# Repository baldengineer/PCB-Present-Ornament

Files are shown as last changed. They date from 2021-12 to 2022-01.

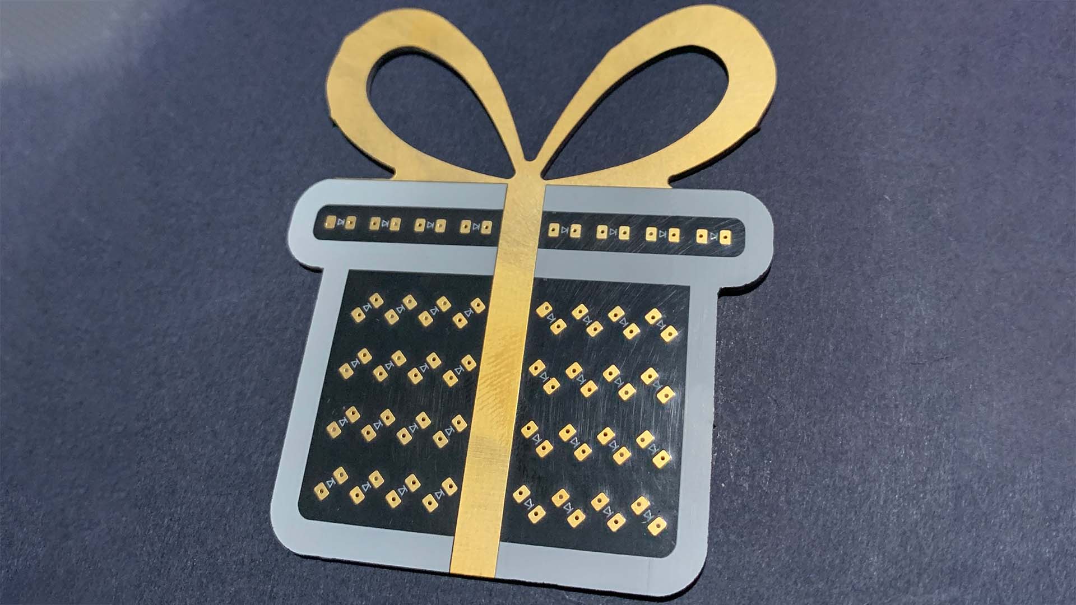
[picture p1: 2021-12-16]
images/pcb-present-oshpark-after-dark.jpg

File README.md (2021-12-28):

Present in OSH Park After Dark

## KiCad Present / Ornament
KiCad stuff.

## Warning: JST is not compatible with Adafruit batteries. + and - are reversed :(

* LED Matrix
* ATmega8 (328) based
* Powered by LiPo
* Programmed with ISP Header
* hand it with a string around the ribbon loops

## Bald Engineer Live Stream
Watch the stream and help out in chat here:
https://twitch.tv/baldengineer

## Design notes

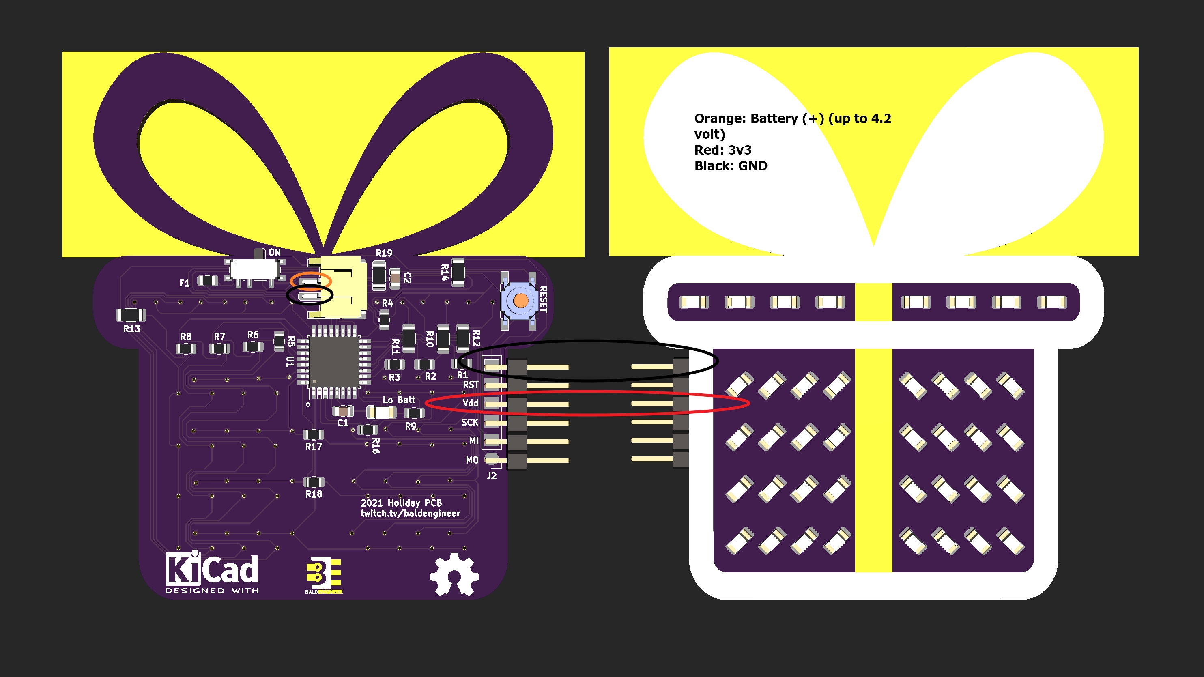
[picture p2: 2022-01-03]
images/powering pcb present annotated.jpg

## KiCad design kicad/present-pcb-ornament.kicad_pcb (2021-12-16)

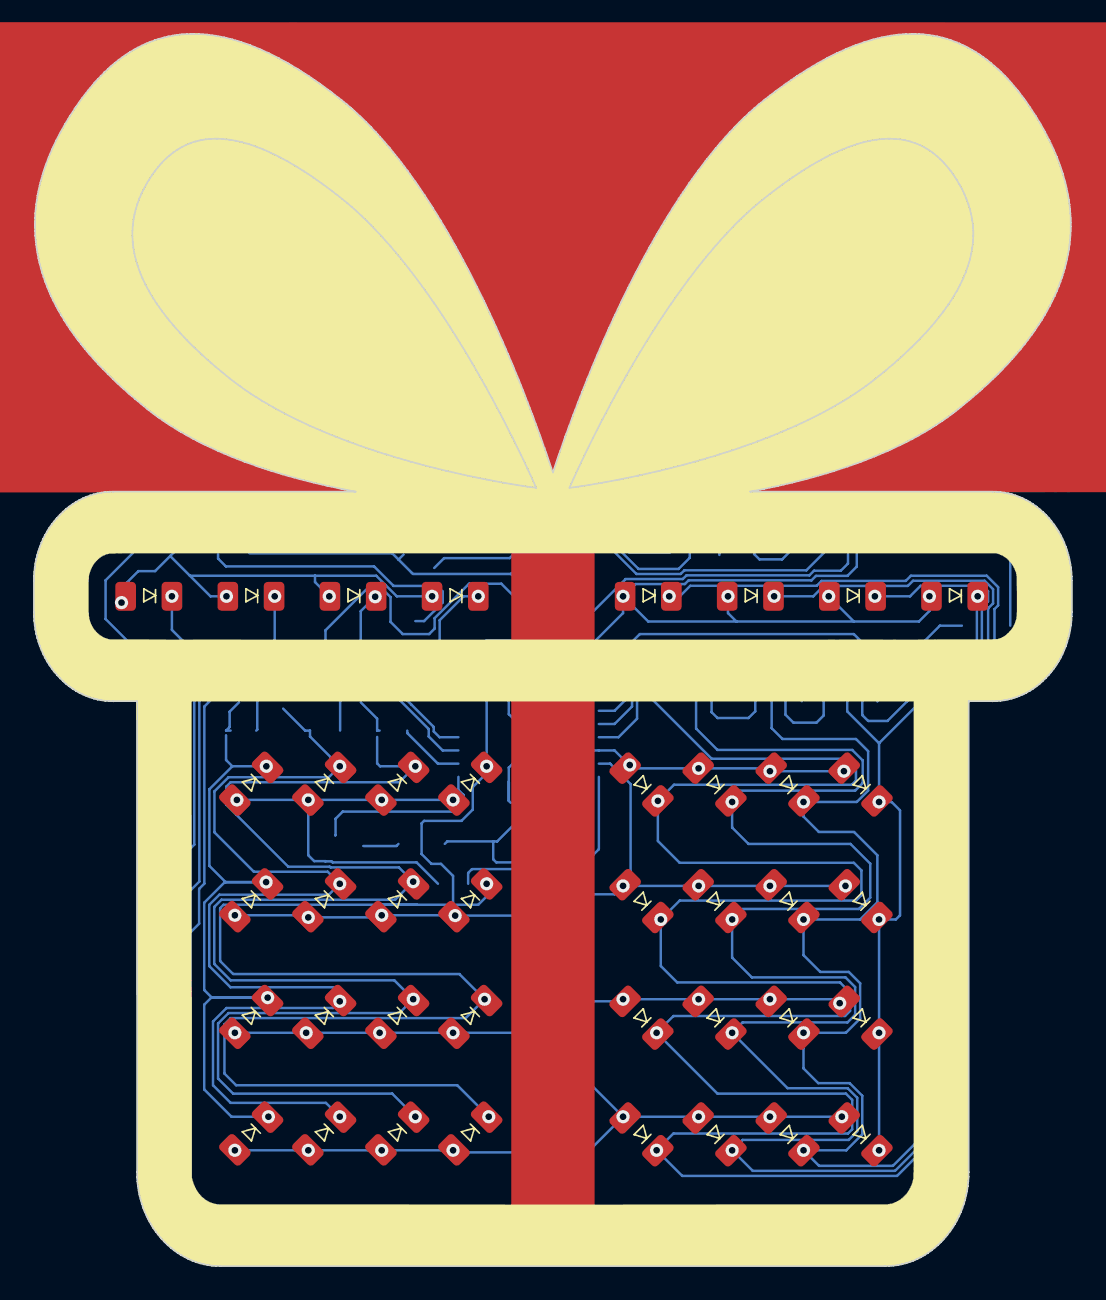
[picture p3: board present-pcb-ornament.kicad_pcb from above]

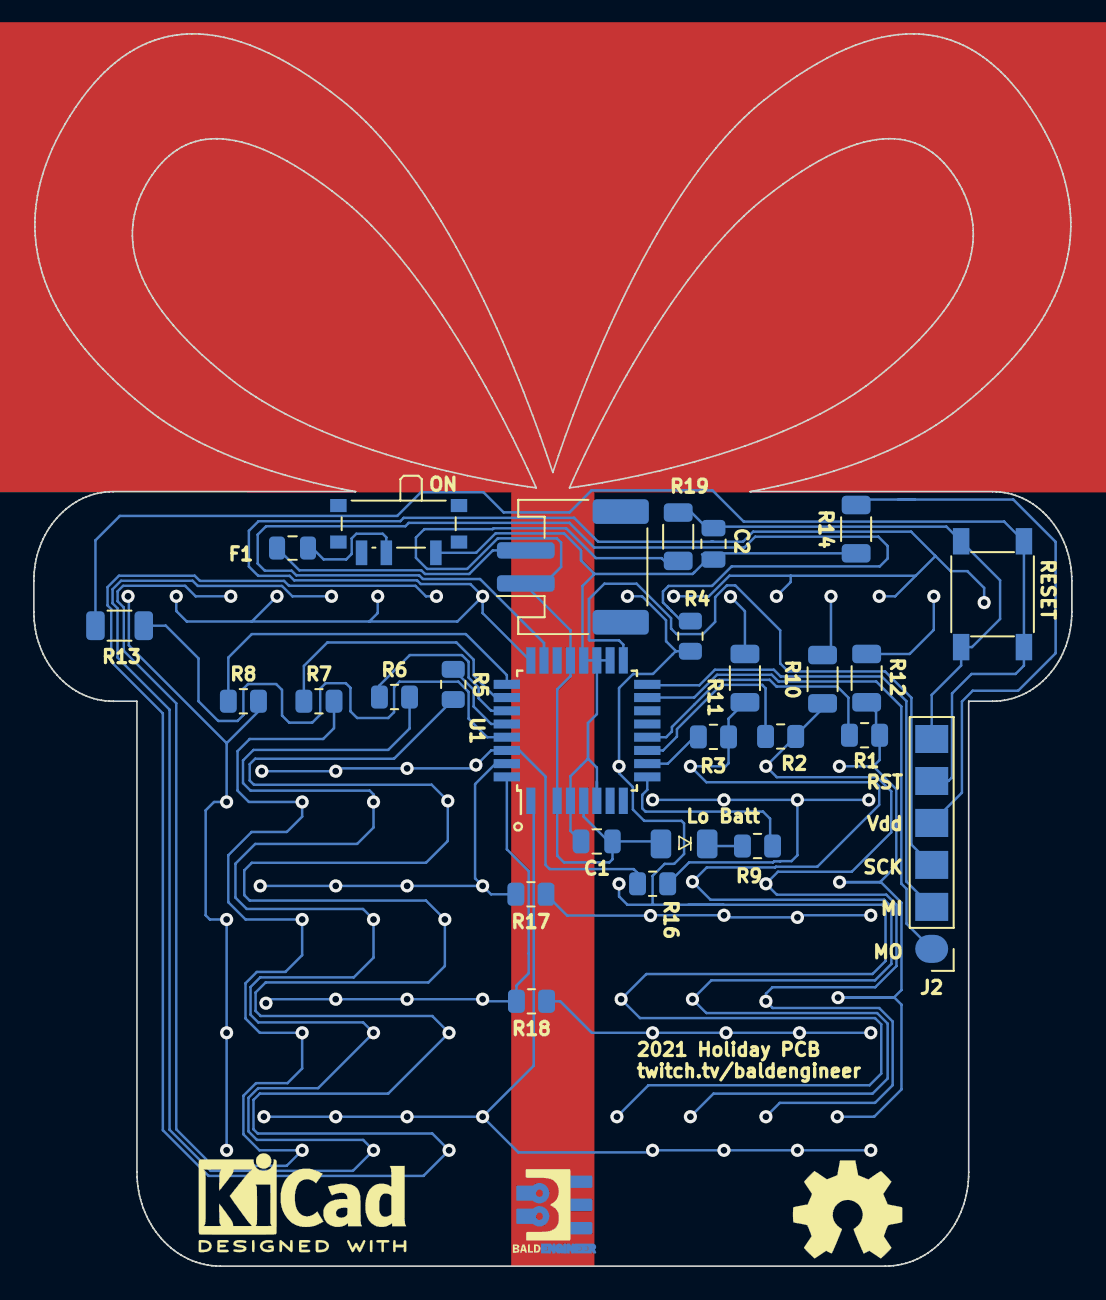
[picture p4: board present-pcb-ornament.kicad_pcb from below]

Board: 2 copper layers, 62.8 x 74.6 mm, 69 parts (28 on the bottom side), 31 nets.

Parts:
C1, C2: 10u; C_0805_2012Metric
D1, D34, D35, D36, D37, D38, D39, D40, D41: RED; LED_1206_3216Metric-NoSilk
D2, D3, D4, D5, D6, D7, D8, D9, D10, D11, D12, D13, D14, D15, D16, D17, D18, D19, D20, D21, D22, D23, D24, D25, D26, D27, D28, D29, D30, D31, D32: GRN; LED_1206_3216Metric-NoSilk
D33: Batt; LED_1206_3216Metric-NoSilk
F1: 200mA; Fuse_0805_2012Metric
H1: PCB; inky escaped
J1: Batt; JST_PH_S2B-PH-SM4-TB_1x02-1MP_P2.00mm_Horizontal
J2: ISP; PinHeader_1x06_P2.54mm_SMD_Field
R1, R2, R3, R4, R5, R6, R7, R8: R_0805; R_0805_2012Metric
R9: 1K; R_0805_2012Metric
R10, R11, R12, R13, R14, R19: 0; R_1206_3216Metric
R16, R17, R18: 0; R_0805_2012Metric
SW1: PWR; SW_SPDT_PCM12-no-mounts
SW2: RESET; SW_Push_CK_PTS525_SM15
U1: ATmega8A-AU; TQFP-32_7x7mm_P0.8mm
svg2mod: G***; BE5v2

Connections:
/Fused: F1.2, SW1.2
/MISO: J2.2, U1.16
/MOSI: J2.1, U1.15
/Pin1: R1.1, U1.12
/Pin2: R2.1, U1.11
/Pin3: R3.1, U1.10
/Pin4: R4.1, U1.23
/Pin5: R5.1, U1.28
/Pin6: R6.1, U1.27
/Pin7: R7.1, U1.26
/Pin8: R8.1, U1.25
/Pin9: D34.1, D35.1, D36.1, D37.1, D38.1, D39.1, D40.1, D41.1, U1.24
/Pin10: D1.1, D5.1, D9.1, D13.1, D17.1, D21.1, D25.1, D29.1, R16.1, R16.2, U1.30
/Pin11: D2.1, D6.1, D10.1, D14.1, D18.1, D22.1, D26.1, D30.1, R17.1, R17.2, U1.31
/Pin12: D3.1, D7.1, D11.1, D15.1, D19.1, D23.1, D27.1, D31.1, R18.1, R18.2, U1.32
/Pin13: D4.1, D8.1, D12.1, D16.1, D20.1, D24.1, D28.1, D32.1, U1.1
/Pin17: R9.2, U1.9
/RESET: J2.5, R13.1, R13.2, SW2.2, U1.29
/SCK: J2.3, U1.17
/Vin: F1.1, J1.2
/nR1: D1.2, D2.2, D3.2, D4.2, D34.2, R1.2, R12.1, R12.2
/nR2: D5.2, D6.2, D7.2, D8.2, D35.2, R2.2, R10.1, R10.2
/nR3: D9.2, D10.2, D11.2, D12.2, D36.2, R3.2, R11.1, R11.2
/nR4: D13.2, D14.2, D15.2, D16.2, D37.2, R4.2
/nR5: D17.2, D18.2, D19.2, D20.2, D38.2, R5.2
/nR6: D21.2, D22.2, D23.2, D24.2, D39.2, R6.2
/nR7: D25.2, D26.2, D27.2, D28.2, D40.2, R7.2
/nR8: D29.2, D30.2, D31.2, D32.2, D41.2, R8.2
GND: C1.2, C2.2, D33.1, J1.1, J2.6, R19.1, R19.2, SW2.1, U1.3, U1.5, U1.21
unnamed: D33.2, R9.1
VDD: C1.1, C2.1, J2.4, R14.1, R14.2, SW1.1, U1.4, U1.6, U1.18, U1.19, U1.20

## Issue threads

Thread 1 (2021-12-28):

Battery JST is backward

baldengineer, 2021-12-28:
The JST connector is reversed from Adafruit's "standard" pinout. So... don't plug Adafruit batteries in without making an adapter. :)

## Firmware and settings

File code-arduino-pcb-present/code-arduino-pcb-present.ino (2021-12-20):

// Bald Engineer's Live PCB Present Ornament
// James Lewis (C) 2021
// MIT License

// Get the MiniCore Board Definitions! 
// Boards have a 168P or 328PB 3v3 @ 8 MHz
// We're going to run with internal RC oscillator
//
// The PCBs have 40 LEDs configured as a matrix with 
// 8 columns and 5 rows. Code below turns on two LEDs
// at a time. Direct port manipulation limits the flicker.

// #include<EEPROM.h>

// Define the pinouts
// Rows
// PCB: Pin9, Pin10, Pin11, Pin12, Pin13
// AVR: PC1,  PD0,   PD1,   PD2,   PD3
// Uno: A1,    0,     1,     2,     3
const byte row_count = 5;
const byte rows[row_count] = {A1,0,1,2,3};

// Cols
// PCB: Pin1, Pin2, Pin3, Pin4, Pin5, Pin6, Pin7, Pin8
// AVR: PB0,  PD7,  PD6,  PC0,  PC5,  PC4,  PC3,  PC2
// Uno:   8,    7,    6,    A0,  A5,   A4,   A3,   A2
const byte col_count = 8;
const byte cols[8] = {8,7,6,A0,A5,A4,A3,A2};

// Pointless Battery Stuff
// Just realized, I tied AREF to ADC6
// batt_pointless has a LED, so it can be used for debug
const byte batt_facepalm = A6; // ADC
const byte batt_pointless = 5; // PD5

uint8_t mode = 0; // was going to cycle patterns on boot

// Cols    0     1     2     3     4    5      6     7
// PCB: Pin1, Pin2, Pin3, Pin4, Pin5, Pin6, Pin7, Pin8
// AVR: PB0,  PD7,  PD6,  PC0,  PC5,  PC4,  PC3,  PC2
// Uno:   8,    7,    6,    A0,  A5,   A4,   A3,   A2
void drive_col(int row, unsigned long led_wait_time) {
  pinMode(row, OUTPUT);
  digitalWrite(row, LOW);

  // we have plenty of flash memory available

  // DDR = 1 is out, 0 is in  
  // col Pin1 PB0
  DDRB = DDRB | 0x01; // col is out
  PORTB = PORTB | 0x01; // turn it on
  delayMicroseconds(led_wait_time);
  DDRB = DDRB & 0xFE; // col is in

  // col Pin2 PD7
  DDRD = DDRD | 0x80; // col is out
  PORTD = PORTD | 0x80; // turn it on
  delayMicroseconds(led_wait_time);
  DDRD = DDRD & 0x7F; // col is in 

  // col Pin3 PD6
  DDRD = DDRD | 0x40; // col is out
  PORTD = PORTD | 0x40; // turn it on
  delayMicroseconds(led_wait_time);
  DDRD = DDRD & 0xBF; // col is in 

  // col Pin4 PC0
  DDRC = DDRC | 0x01; // col is out
  PORTC = PORTC | 0x01; // turn it on
  delayMicroseconds(led_wait_time);
  DDRC = DDRC & 0xFE; // col is in 

  // col Pin5 PC5
  DDRC = DDRC | 0x20; // col is out
  PORTC = PORTC | 0x20; // turn it on
  delayMicroseconds(led_wait_time);
  DDRC = DDRC & 0xDF; // col is in 

  // col Pin6 PC4
  DDRC = DDRC | 0x10; // col is out
  PORTC = PORTC | 0x10; // turn it on
  delayMicroseconds(led_wait_time);
  DDRC = DDRC & 0xEF; // col is in 

  // col Pin7 PC3
  DDRC = DDRC | 0x08; // col is out
  PORTC = PORTC | 0x08; // turn it on
  delayMicroseconds(led_wait_time);
  DDRC = DDRC & 0xF7; // col is in 
  
  // col Pin8 PC2
  DDRC = DDRC | 0x04; // col is out
  PORTC = PORTC | 0x04; // turn it on
  delayMicroseconds(led_wait_time);
  DDRC = DDRC & 0xFB; // col is in 

  pinMode(row, INPUT);
}

void setup() {
  mode = -1; // eventually replace with EEPROM code
}

void loop() {
 for (int row=0; row < row_count; row++) {
    drive_col(rows[row], 250);
  }
}

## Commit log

2021-12-16 initial commit (project already fabbed)
    [present-pcb-ornament.kicad_pcb, present-pcb-ornament.sch]
2021-12-20 Some initial Arduino code, totally untested.
2022-01-03 Added image to document where to connect power.
